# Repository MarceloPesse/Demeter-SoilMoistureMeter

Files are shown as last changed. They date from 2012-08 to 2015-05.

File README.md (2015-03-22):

Ah, the good old times.

This here is the final project for my Bachelor's degree in electrical engineering.
The group was composed of:
  - Marcelo Pesse a.k.a. Me
  - Ricardo Bonfá Alberico 
  - Jhonston Dalcin

This project is basically an Arduino Leonardo with a 4-chanel 18-bit resolution ADC and an Xbee module.
For the sensor we used an EC-5 soil moisture sensor from Decagon.
(http://www.decagon.com/products/soils/volumetric-water-content-sensors/ec-5-soil-moisture-small-area-of-influence/)

The hardware sends all the info via an XBee module to a PC running a Daemon.
The Daemon then sends the data to a server and everybody is happy.

This project was made 3 years ago, so it’s probably not my best work.

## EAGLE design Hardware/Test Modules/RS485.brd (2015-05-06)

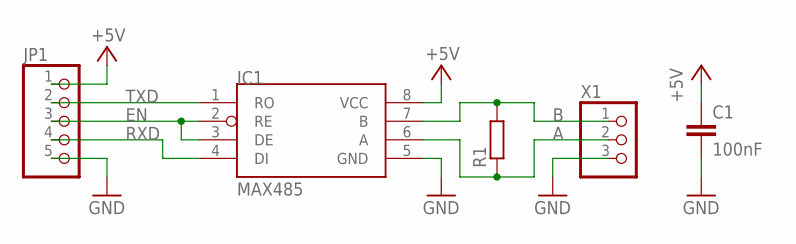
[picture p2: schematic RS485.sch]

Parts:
C1: 100nF; C0805K
IC1: MAX485; SO08
JP1: PINHD-1X5; 1X05
R1: R-EU_R0805; R0805
X1: W237-103

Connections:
+5V: C1.1, IC1.8 (VCC), JP1.1
A: IC1.6 (A), R1.1, X1.2
B: IC1.7 (B), R1.2, X1.1
EN: IC1.2 (RE), IC1.3 (DE), JP1.3
GND: C1.2, IC1.5 (GND), JP1.5, X1.3
RXD: IC1.4 (DI), JP1.4
TXD: IC1.1 (RO), JP1.2

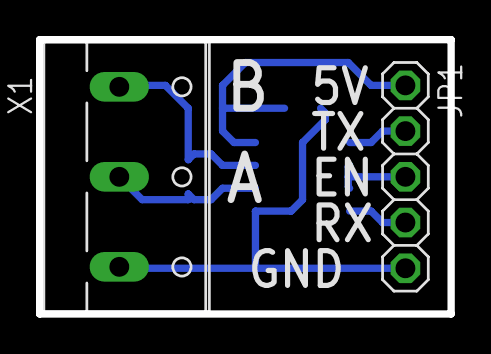
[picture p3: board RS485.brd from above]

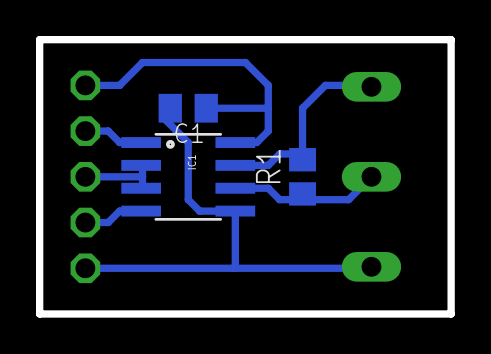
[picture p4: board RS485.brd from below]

Board: 2 copper layers, 22.9 x 15.2 mm, 5 parts (3 on the bottom side), 7 nets.

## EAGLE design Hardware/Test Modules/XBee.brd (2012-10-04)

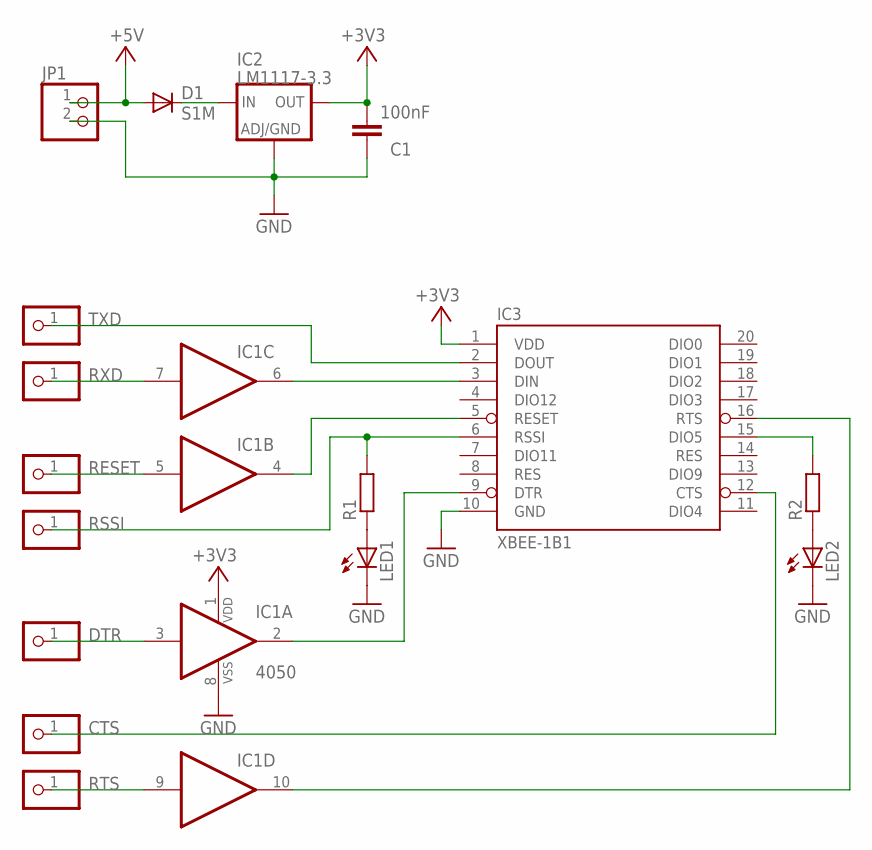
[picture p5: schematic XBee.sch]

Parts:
C1: 100nF; C0805K
D1: S1M; DO-214AC
IC1: 4050; SO16
IC2: LM1117-3.3; SOT223
IC3: XBEE-1B1; XBEE-1
JP1: PINHD-1X2; 1X02
JP2: TXD; 1X01
JP3: RXD; 1X01
JP4: RST; 1X01
JP5: RSSI; 1X01
JP6: DTR; 1X01
JP7: CTS; 1X01
JP8: RTS; 1X01
LED1, LED2: LED3MM
R1, R2: R-EU_R0805; R0805

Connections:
+3V3: C1.2, IC1.1 (VDD), IC2.2 (OUT), IC2.4 (OUT), IC3.1 (VDD)
+5V: D1.A, JP1.1
CTS: IC3.12 (CTS), JP7.1
DTR: IC1.3 (I), JP6.1
GND: C1.1, IC1.8 (VSS), IC2.1 (ADJ), IC3.10 (GND), JP1.2, LED1.K (C), LED2.K (C)
unnamed: D1.C, IC2.3 (IN)
unnamed: IC1.6 (O), IC3.3 (DIN)
unnamed: IC1.4 (O), IC3.5 (RESET)
unnamed: LED1.A, R1.1
unnamed: IC1.2 (O), IC3.9 (DTR)
unnamed: IC1.10 (O), IC3.16 (RTS)
unnamed: LED2.A, R2.1
unnamed: IC3.15 (DIO5), R2.2
RESET: IC1.5 (I), JP4.1
RSSI: IC3.6 (RSSI), JP5.1, R1.2
RTS: IC1.9 (I), JP8.1
RXD: IC1.7 (I), JP3.1
TXD: IC3.2 (DOUT), JP2.1

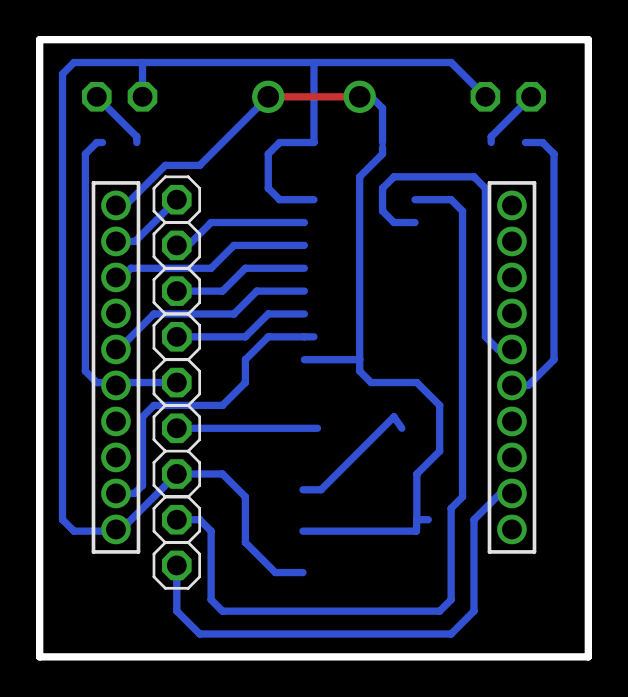
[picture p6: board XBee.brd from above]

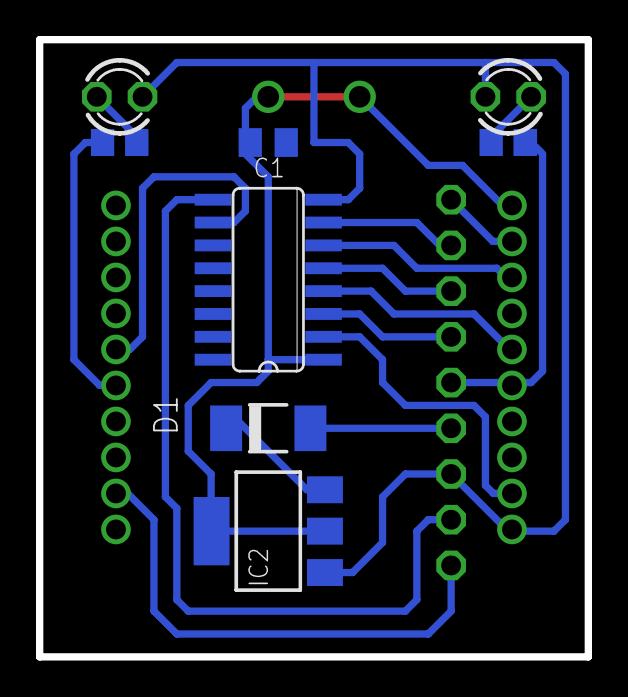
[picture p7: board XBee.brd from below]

Board: 2 copper layers, 30.5 x 34.3 mm, 17 parts (8 on the bottom side), 18 nets.

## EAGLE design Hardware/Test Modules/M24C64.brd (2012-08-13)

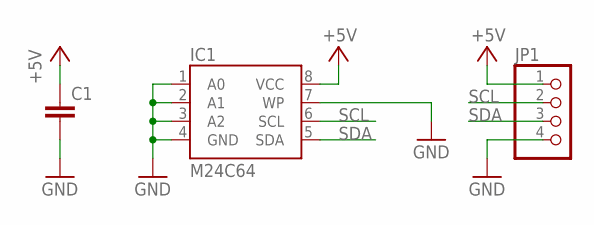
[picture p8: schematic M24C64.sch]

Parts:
C1: C-EUC0805K; C0805K
IC1: M24C64; SO08
JP1: PINHD-1X4; 1X04

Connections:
+5V: C1.1, IC1.8 (VCC), JP1.1
GND: C1.2, IC1.1 (A0), IC1.2 (A1), IC1.3 (A2), IC1.4 (GND), IC1.7 (WP), JP1.4
SCL: IC1.6 (SCL), JP1.2
SDA: IC1.5 (SDA), JP1.3

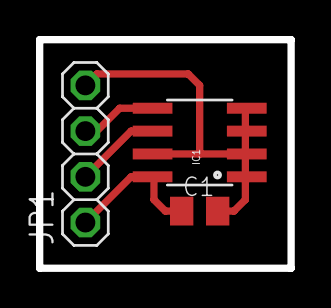
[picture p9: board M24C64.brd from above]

Board: 2 copper layers, 14.0 x 12.7 mm, 3 parts (0 on the bottom side), 4 nets.

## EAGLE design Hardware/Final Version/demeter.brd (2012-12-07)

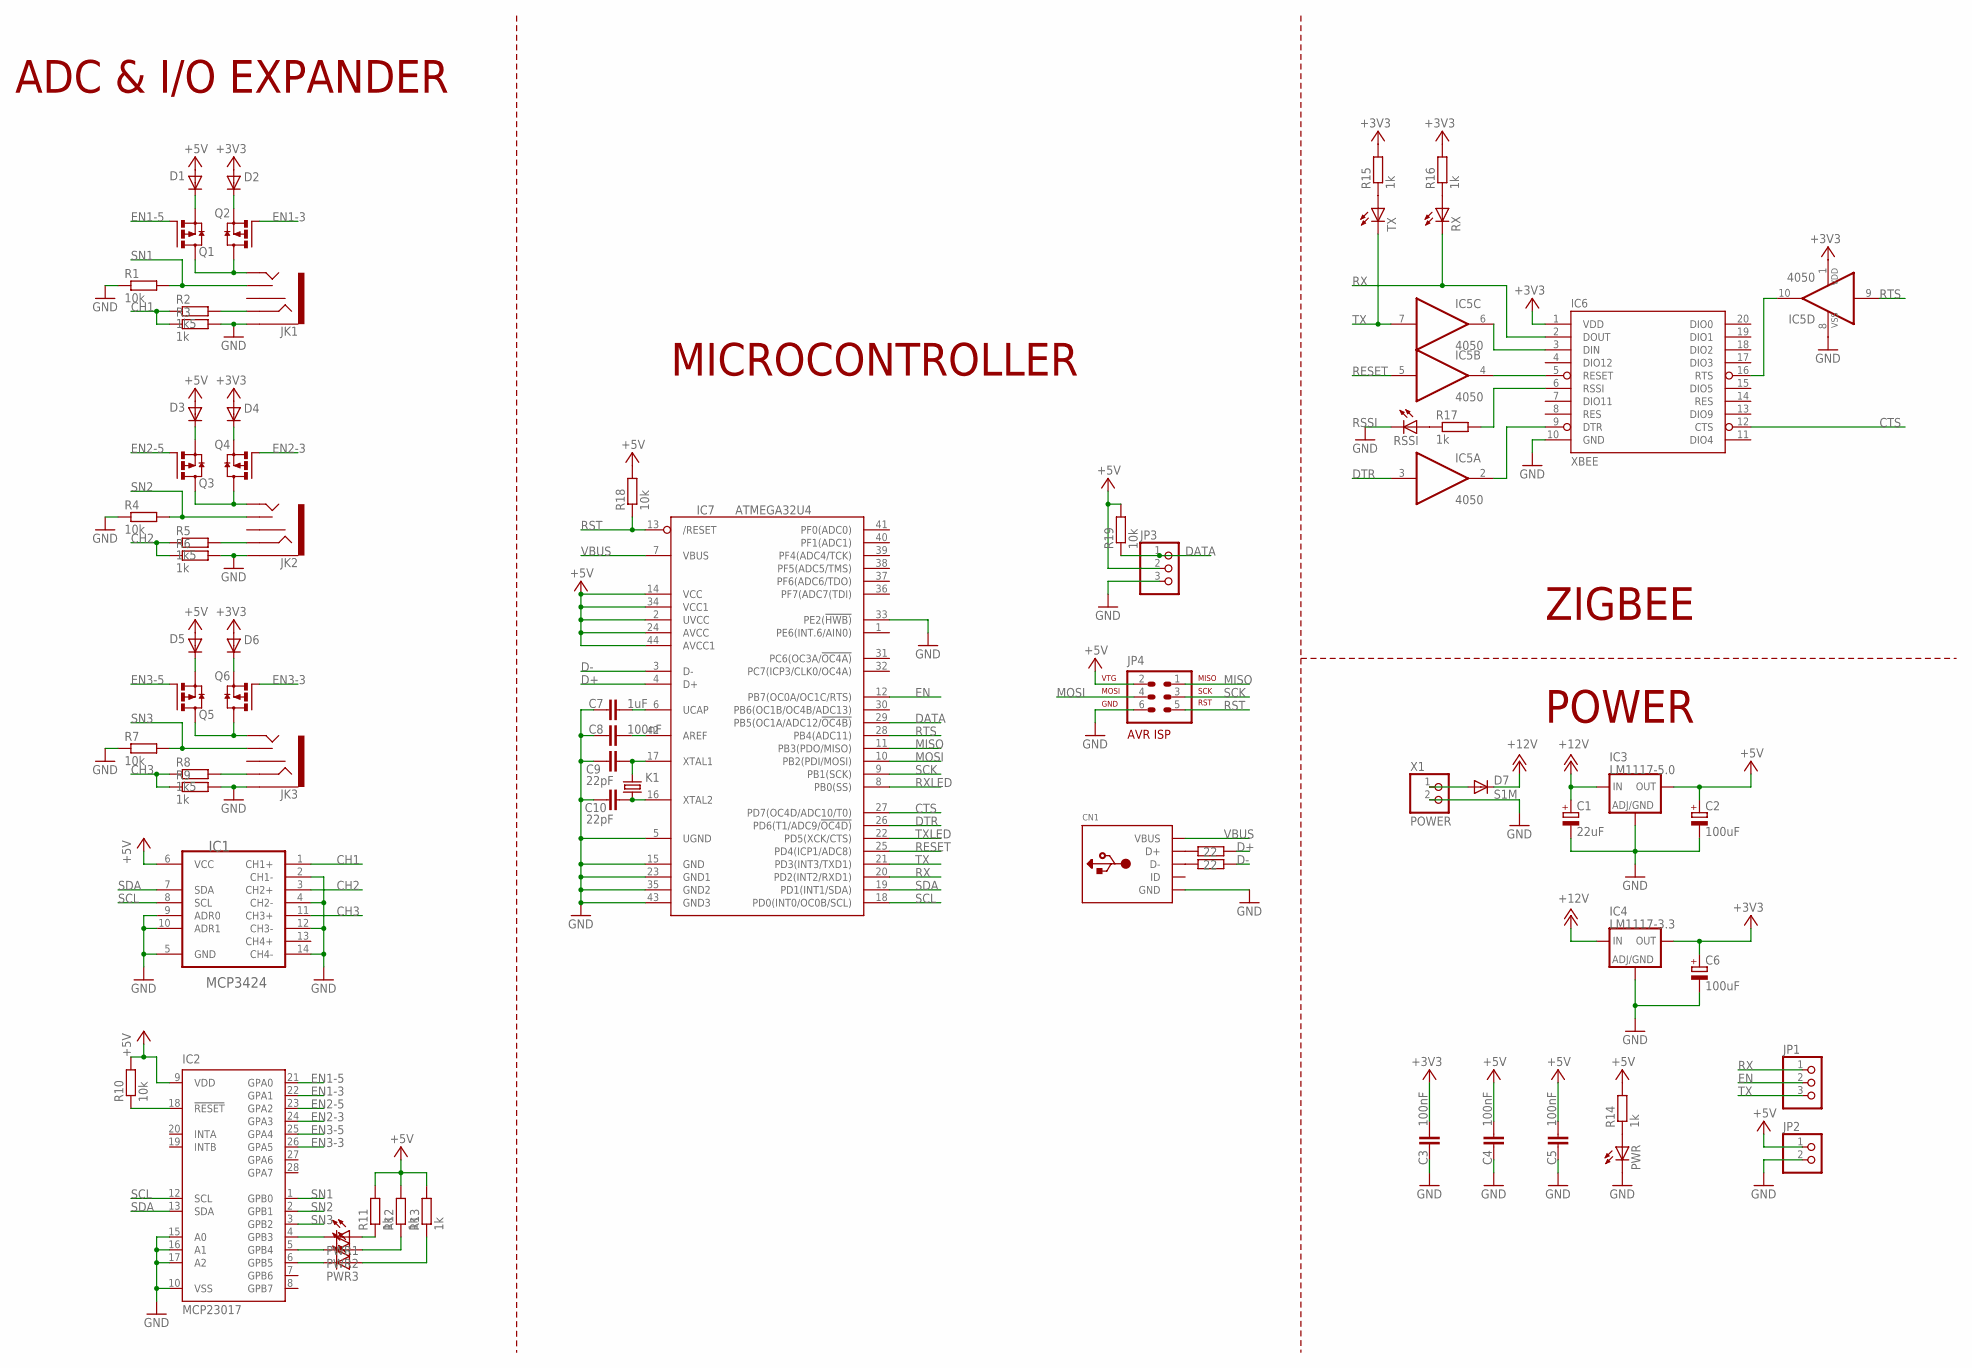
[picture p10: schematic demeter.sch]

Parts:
C1: 22uF; PANASONIC_D
C2, C6: 100uF; PANASONIC_D
C3, C4, C5, C8: 100nF; C0805K
C7: 1uF; C0805K
C9, C10: 22pF; C0805K
CN1: USBMINIB; USB-MINIB
D1, D2, D3, D4, D5, D6: MBR0520; SOD123
D7: S1M; DO-214AC
IC1: MCP3424; TSSOP14
IC2: MCP23017; SO28W
IC3: LM1117-5.0; DPACK
IC4: LM1117-3.3; DPACK
IC5: 4050; SO16
IC6: XBEE; XBEE-1
IC7: ATMEGA32U4; TQFP44
JK1, JK2, JK3: AUDIO-JACK2PTH; AUDIO-JACK
JP1, JP3: PINHD-1X3180; 1X03
JP2: PINHD-1X2; 1X02
JP4: AVR-ISP; AVR-ISP-6
K1: CRYSTALHC49UP; HC49UP
PWR, PWR1, PWR2, PWR3: LED0805; CHIP-LED0805
Q1, Q2, Q3, Q4, Q5, Q6: IRLML6402; SOT23
R1, R4, R7, R10, R18, R19: 10k; R0805
R2, R5, R8: 1k5; R0805
R3, R6, R9, R11, R12, R13, R14, R15, R16, R17: 1k; R0805
R20, R21: 22; R0805
RSSI: LED0805; CHIP-LED0805
RX: LED0805; CHIP-LED0805
TX: LED0805; CHIP-LED0805
X1: POWER; W237-102

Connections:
+3V3: C3.1, C6.+, D2.A, D4.A, D6.A, IC4.4 (OUT), IC5.1 (VDD), IC6.1 (VDD), R15.2, R16.2
+5V: C2.+, C4.1, C5.1, D1.A, D3.A, D5.A, IC1.6 (VCC), IC2.9 (VDD), IC3.4 (OUT), IC7.2 (UVCC), IC7.14 (VCC), IC7.24 (AVCC), IC7.34 (VCC1), IC7.44 (AVCC1), JP2.1, JP3.2, JP4.2 (VTG), R10.2, R11.2, R12.2, R13.2, R14.2, R18.2, R19.2
+12V: C1.+, D7.C, IC3.3 (IN), IC4.3 (IN)
CH1: IC1.1 (CH1+), R2.1, R3.1
CH2: IC1.3 (CH2+), R5.1, R6.1
CH3: IC1.11 (CH3+), R8.1, R9.1
CTS: IC6.12 (CTS), IC7.27 (PD7(OC4D/ADC10/T0))
D+: IC7.4 (D+), R20.1
D-: IC7.3 (D-), R21.1
DATA: IC7.29 (PB5(OC1A/ADC12/!OC4B)), JP3.1, R19.1
DTR: IC5.3 (I), IC7.26 (PD6(T1/ADC9/!OC4D))
EN: IC7.12 (PB7(OC0A/OC1C/RTS)), JP1.2
EN1-3: IC2.22 (GPA1), Q2.1 (G)
EN1-5: IC2.21 (GPA0), Q1.1 (G)
EN2-3: IC2.24 (GPA3), Q4.1 (G)
EN2-5: IC2.23 (GPA2), Q3.1 (G)
EN3-3: IC2.26 (GPA5), Q6.1 (G)
EN3-5: IC2.25 (GPA4), Q5.1 (G)
GND: C1.-, C2.-, C3.2, C4.2, C5.2, C6.-, C7.2, C8.2, C9.2, C10.2, CN1.GND, CN1.GND1 (GND), CN1.GND2 (GND), CN1.GND3 (GND), CN1.GND4 (GND), IC1.2 (CH1-), IC1.4 (CH2-), IC1.5 (GND), IC1.9 (ADR0), IC1.10 (ADR1), IC1.12 (CH3-), IC1.14 (CH4-), IC2.10 (VSS), IC2.15 (A0), IC2.16 (A1), IC2.17 (A2), IC3.1 (ADJ), IC4.1 (ADJ), IC5.8 (VSS), IC6.10 (GND), IC7.5 (UGND), IC7.15 (GND), IC7.23 (GND1), IC7.33 (PE2(!HWB)), IC7.35 (GND2), IC7.43 (GND3), JK1.SLEEVE, JK2.SLEEVE, JK3.SLEEVE, JP2.2, JP3.3, JP4.6 (GND), PWR.C, R1.1, R3.2, R4.1, R6.2, R7.1, R9.2, RSSI.C, X1.2
MISO: IC7.11 (PB3(PDO/MISO)), JP4.1 (MISO)
MOSI: IC7.10 (PB2(PDI/MOSI)), JP4.4 (MOSI)
unnamed: D7.A, X1.1
unnamed: PWR.A, R14.1
unnamed: IC5.6 (O), IC6.3 (DIN)
unnamed: IC5.4 (O), IC6.5 (RESET)
unnamed: PWR3.A, R13.1
unnamed: R17.1, RSSI.A
unnamed: IC5.2 (O), IC6.9 (DTR)
unnamed: IC5.10 (O), IC6.16 (RTS)
unnamed: IC2.6 (GPB5), PWR3.C
unnamed: IC2.4 (GPB3), PWR1.C
unnamed: IC2.18 (!RESET), R10.1
unnamed: JK1.TIP, Q1.3 (D), Q2.3 (D)
unnamed: D1.C, Q1.2 (S)
unnamed: D2.C, Q2.2 (S)
unnamed: JK2.TIP, Q3.3 (D), Q4.3 (D)
unnamed: D3.C, Q3.2 (S)
unnamed: D4.C, Q4.2 (S)
unnamed: JK3.TIP, Q5.3 (D), Q6.3 (D)
unnamed: D5.C, Q5.2 (S)
unnamed: D6.C, Q6.2 (S)
unnamed: PWR2.A, R12.1
unnamed: PWR1.A, R11.1
unnamed: C7.1, IC7.6 (UCAP)
unnamed: C8.1, IC7.42 (AREF)
unnamed: C9.1, IC7.17 (XTAL1), K1.2
unnamed: C10.1, IC7.16 (XTAL2), K1.1
unnamed: CN1.D+, R20.2
unnamed: CN1.D-, R21.2
unnamed: JK1.RING, R2.2
unnamed: JK2.RING, R5.2
unnamed: IC2.5 (GPB4), PWR2.C
unnamed: JK3.RING, R8.2
unnamed: R15.1, TX.A
unnamed: R16.1, RX.A
RESET: IC5.5 (I), IC7.25 (PD4(ICP1/ADC8))
RSSI: IC6.6 (RSSI), R17.2
RST: IC7.13 (/RESET), JP4.5 (RST), R18.1
RTS: IC5.9 (I), IC7.28 (PB4(ADC11))
RX: IC6.2 (DOUT), IC7.20 (PD2(INT2/RXD1)), JP1.1, RX.C
RXLED: IC7.8 (PB0(SS))
SCK: IC7.9 (PB1(SCK)), JP4.3 (SCK)
SCL: IC1.8 (SCL), IC2.12 (SCL), IC7.18 (PD0(INT0/OC0B/SCL))
SDA: IC1.7 (SDA), IC2.13 (SDA), IC7.19 (PD1(INT1/SDA))
SN1: IC2.1 (GPB0), JK1.TSH, R1.2
SN2: IC2.2 (GPB1), JK2.TSH, R4.2
SN3: IC2.3 (GPB2), JK3.TSH, R7.2
TX: IC5.7 (I), IC7.21 (PD3(INT3/TXD1)), JP1.3, TX.C
TXLED: IC7.22 (PD5(XCK/CTS))
VBUS: CN1.VBUS, IC7.7 (VBUS)

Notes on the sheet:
ADC & I/O EXPANDER
ZIGBEE
POWER
MICROCONTROLLER

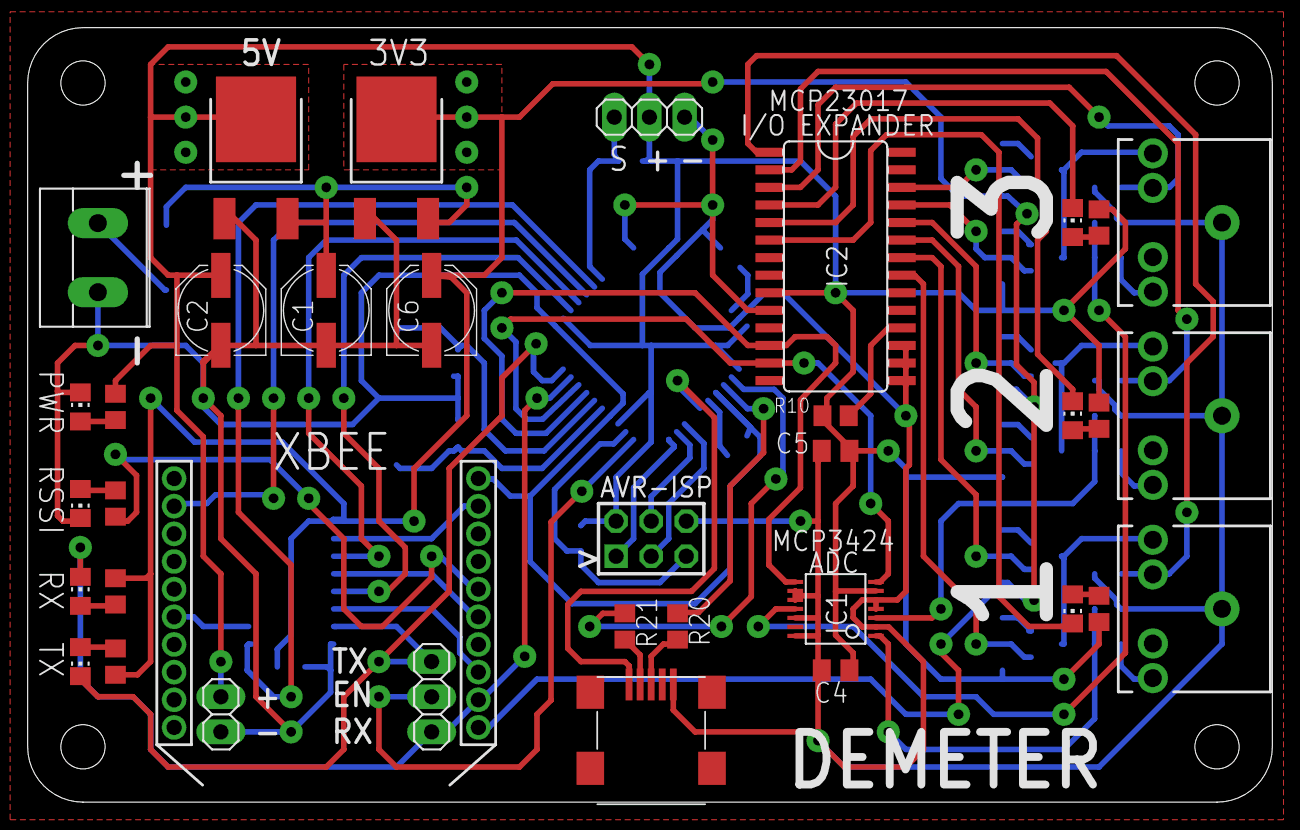
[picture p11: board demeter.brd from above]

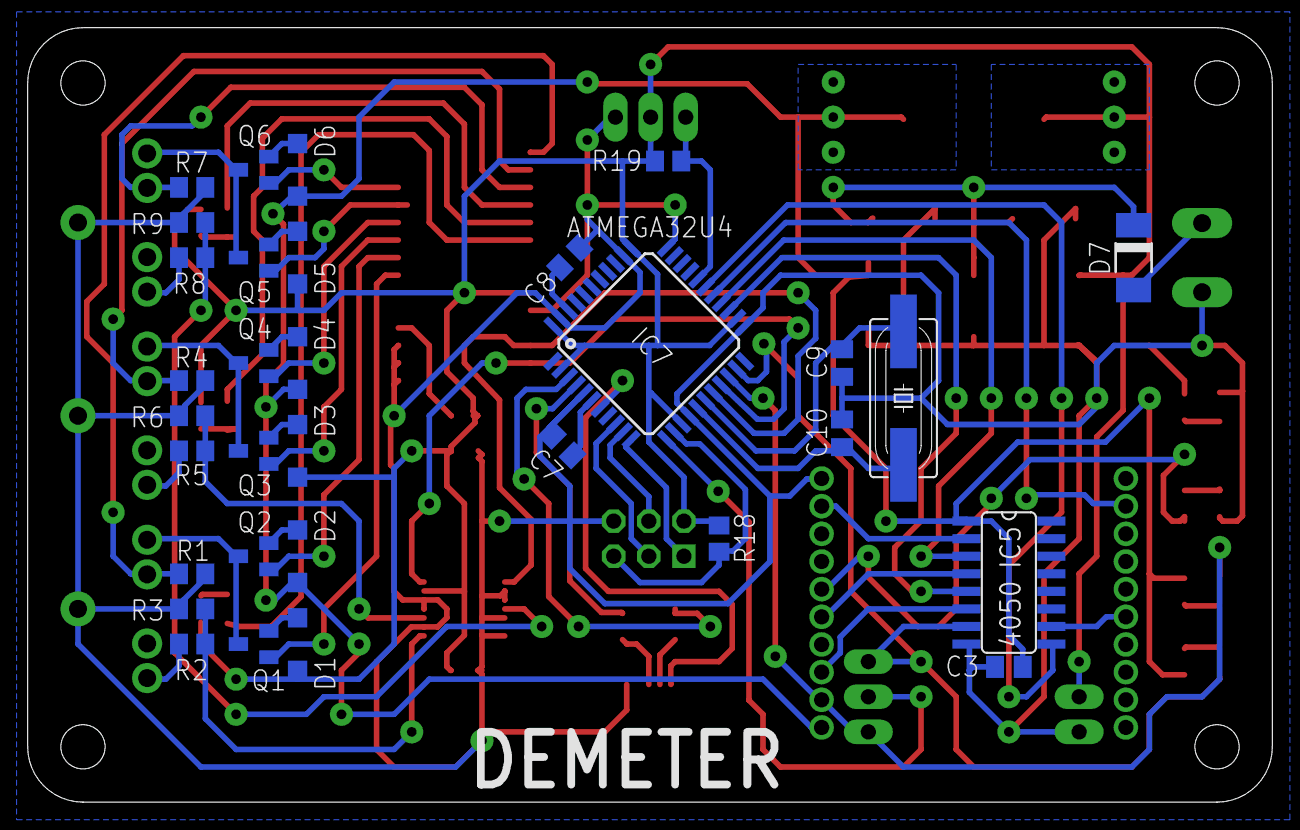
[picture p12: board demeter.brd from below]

Board: 2 copper layers, 90.0 x 56.0 mm, 69 parts (32 on the bottom side), 68 nets.

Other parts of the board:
U$6: DP9056_V1

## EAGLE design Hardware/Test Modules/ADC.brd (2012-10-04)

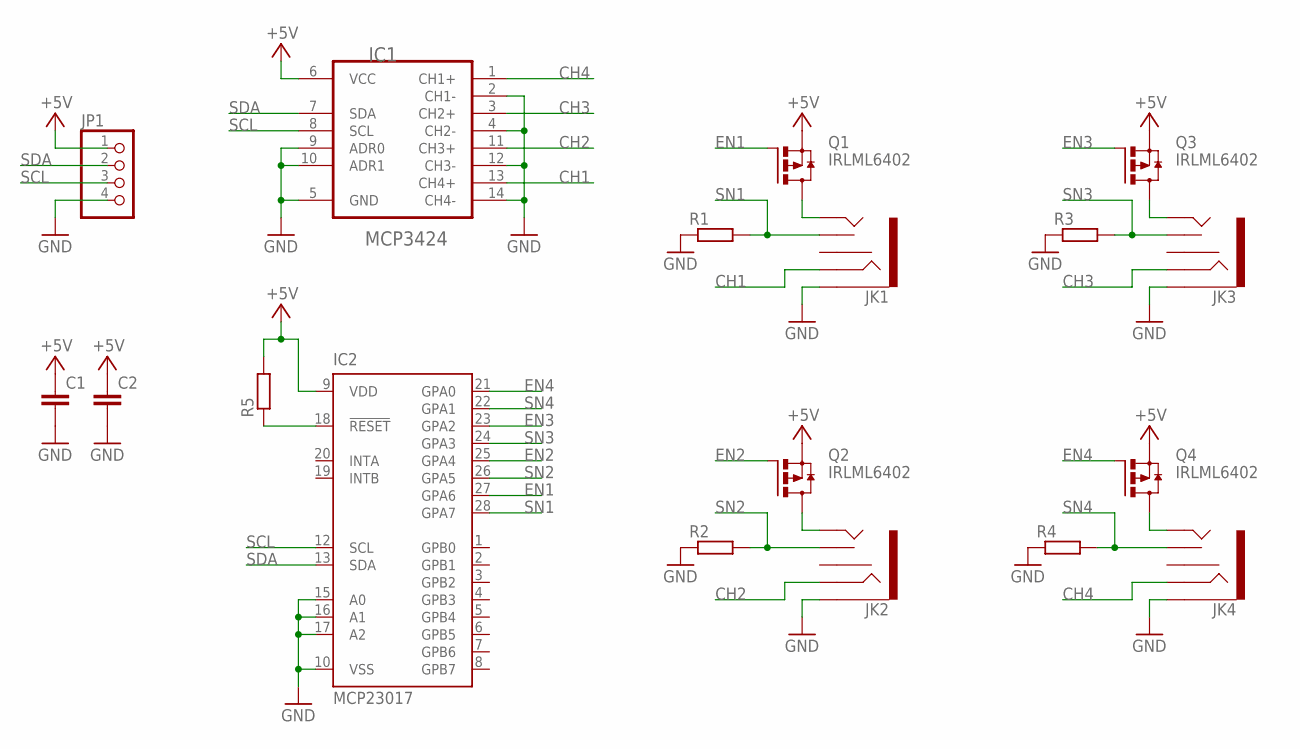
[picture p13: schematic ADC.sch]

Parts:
C1, C2: C-EUC0805K; C0805K
IC1: MCP3424; SO14
IC2: MCP23017; SO28W
JK1, JK2, JK3, JK4: AUDIO-JACK2PTH; AUDIO-JACK
JP1: PINHD-1X4; 1X04
Q1, Q2, Q3, Q4: IRLML6402; SOT23
R1, R2, R3, R4, R5: R-EU_R0805; R0805

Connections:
+5V: C1.1, C2.1, IC1.6 (VCC), IC2.9 (VDD), JP1.1, Q1.2 (S), Q2.2 (S), Q3.2 (S), Q4.2 (S), R5.2
CH1: IC1.13 (CH4+), JK1.RING
CH2: IC1.11 (CH3+), JK2.RING
CH3: IC1.3 (CH2+), JK3.RING
CH4: IC1.1 (CH1+), JK4.RING
EN1: IC2.27 (GPA6), Q1.1 (G)
EN2: IC2.25 (GPA4), Q2.1 (G)
EN3: IC2.23 (GPA2), Q3.1 (G)
EN4: IC2.21 (GPA0), Q4.1 (G)
GND: C1.2, C2.2, IC1.2 (CH1-), IC1.4 (CH2-), IC1.5 (GND), IC1.9 (ADR0), IC1.10 (ADR1), IC1.12 (CH3-), IC1.14 (CH4-), IC2.10 (VSS), IC2.15 (A0), IC2.16 (A1), IC2.17 (A2), JK1.SLEEVE, JK2.SLEEVE, JK3.SLEEVE, JK4.SLEEVE, JP1.4, R1.1, R2.1, R3.1, R4.1
unnamed: JK1.TIP, Q1.3 (D)
unnamed: IC2.18 (!RESET), R5.1
unnamed: JK2.TIP, Q2.3 (D)
unnamed: JK3.TIP, Q3.3 (D)
unnamed: JK4.TIP, Q4.3 (D)
SCL: IC1.8 (SCL), IC2.12 (SCL), JP1.3
SDA: IC1.7 (SDA), IC2.13 (SDA), JP1.2
SN1: IC2.28 (GPA7), JK1.TSH, R1.2
SN2: IC2.26 (GPA5), JK2.TSH, R2.2
SN3: IC2.24 (GPA3), JK3.TSH, R3.2
SN4: IC2.22 (GPA1), JK4.TSH, R4.2



Board: 2 copper layers, 54.6 x 50.8 mm, 18 parts (13 on the bottom side), 21 nets.

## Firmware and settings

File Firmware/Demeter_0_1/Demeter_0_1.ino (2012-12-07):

#include <Wire.h>
#include <EEPROM.h>

#include <DemeterMCP.h>
#include <DemeterADC.h>
#include <DemeterDHT.h>
#include <DemeterCOM.h>

#include "DemeterPIN.h"

demeterMCP mcp;
demeterADC adc;
demeterDHT dht;
demeterCOM com;

String id;

//Board{sen1,ten1,sen2,ten2,sen3,ten3}
Board board = { EEPROM.read(EE_SEN1), EEPROM.read(EE_TEN1),
                EEPROM.read(EE_SEN2), EEPROM.read(EE_TEN2),
                EEPROM.read(EE_SEN3), EEPROM.read(EE_TEN3) };

//Sensor{v5,v3,led,sen,adc}
Sensor sensor1 = {SEN_5V1, SEN_3V1, SEN_LED1, SEN_SN1, SEN_ADC1 };
Sensor sensor2 = {SEN_5V2, SEN_3V2, SEN_LED2, SEN_SN2, SEN_ADC2 };
Sensor sensor3 = {SEN_5V3, SEN_3V3, SEN_LED3, SEN_SN3, SEN_ADC3 };

#define b_max 4
char buff[b_max+1];

void setup() {
  com.begin(XBEE_RESET, RS485_EN);
  mcp.begin();
  dht.begin(SEN_DHT);
  
  sensorBegin(&sensor1);
  sensorBegin(&sensor2);
  sensorBegin(&sensor3);
  
  /*
  EEPROM.write(EE_BOARD, 1);
  EEPROM.write(EE_SEN1, 3);
  EEPROM.write(EE_TEN1, 3);
  EEPROM.write(EE_SEN2, 0);
  EEPROM.write(EE_TEN2, 3);
  EEPROM.write(EE_SEN3, 0);
  EEPROM.write(EE_TEN3, 3);
  */
  
  id = String(EEPROM.read(EE_BOARD), HEX);
  if(EEPROM.read(EE_BOARD) < 16){
    id.concat(id[0]);
    id.setCharAt(0, '0');
  }
  id.toUpperCase();
}

void loop() {
  while (Serial1.available() > 0){
    for(int i = 0; i < b_max; i++){
      buff[i] = buff[i+1];
    }
    buff[b_max] = Serial1.read();
    if(buff[0] == '#' & buff[1] == id[0] & buff[2] == id[1] & buff[3] == ':'){
      if(buff[4] == '1') com.sensor(EEPROM.read(EE_BOARD), 1, board.sen1, sensorRead(&sensor1, board.ten1)/2 );
      if(buff[4] == '2') com.sensor(EEPROM.read(EE_BOARD), 2, board.sen2, sensorRead(&sensor2, board.ten2)/2 );
      if(buff[4] == '3') com.sensor(EEPROM.read(EE_BOARD), 3, board.sen3, sensorRead(&sensor3, board.ten3)/2 );
      if(buff[4] == '4') com.sensor(EEPROM.read(EE_BOARD), 4, 1, dht.temperature() );
      if(buff[4] == '5') com.sensor(EEPROM.read(EE_BOARD), 5, 2, dht.humidity() );
    }
  }
}

void sensorBegin (Sensor* sensor){
  mcp.pinMode(sensor->v5, OUTPUT);
  mcp.pinMode(sensor->v3, OUTPUT);
  mcp.pinMode(sensor->led, OUTPUT);
  mcp.pinMode(sensor->sen, INPUT);

  mcp.digitalWrite(sensor->v5, HIGH);
  mcp.digitalWrite(sensor->v3, HIGH);
  mcp.digitalWrite(sensor->led, HIGH);
}

int32_t sensorRead (Sensor* sensor, byte tensao){
  mcp.digitalWrite(sensor->led, LOW);
  
  if (tensao == 5) mcp.digitalWrite(sensor->v5, LOW);
  else mcp.digitalWrite(sensor->v3, LOW);
  
  delay(10);
  
  int32_t data;
  adc.config(sensor->adc);
  if (!adc.read(data)) Serial.print("Error");
  
  mcp.digitalWrite(sensor->v5, HIGH);
  mcp.digitalWrite(sensor->v3, HIGH);
  
  mcp.digitalWrite(sensor->led, HIGH);
  
  return data;
}

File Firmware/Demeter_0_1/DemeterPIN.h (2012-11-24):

#define XBEE_RESET 4
#define XBEE_DTR 12
#define XBEE_CTS 6
#define XBEE_RTS 8

#define SEN_DHT 9

#define RS485_EN 11

#define SEN_LED1 13
#define SEN_LED2 12
#define SEN_LED3 11
#define SEN_SN1 8
#define SEN_SN2 9
#define SEN_SN3 10

#define SEN_5V1 0
#define SEN_3V1 1
#define SEN_5V2 2
#define SEN_3V2 3
#define SEN_5V3 4
#define SEN_3V3 5

#define SEN_ADC1 1
#define SEN_ADC2 2
#define SEN_ADC3 3

#define EE_BOARD 0
#define EE_SEN1 1
#define EE_TEN1 2
#define EE_SEN2 3
#define EE_TEN2 4
#define EE_SEN3 5
#define EE_TEN3 6

struct Sensor{
  uint8_t v5;
  uint8_t v3;
  uint8_t led;
  uint8_t sen;
  uint8_t adc;
};

struct Board{
  uint8_t sen1;
  uint8_t ten1;
  uint8_t sen2;
  uint8_t ten2;
  uint8_t sen3;
  uint8_t ten3;
};

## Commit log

2012-11-19 Inclusão da última versão do SI (integrada com parte gráfica, faltando principalmente correção do jquery do setor e o sistema de mapas da fazenda, além de funcionalidades "opcionais" como previsão do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
2012-11-24 deletando tudo do SI pois não conseguia dar commit, proximo tera tudo de novo
2012-11-24 coltando SI para dar certo commit. nessa versão tem o gráfico puxando dados direto do banco, problema com jquery resolvido
2012-11-29 models modificado para atender as novas mudancas de integracao com C#
2012-12-05 pagina da fazenda busca por todos os setores e mostra no mapa suas posicoes e cores baseadas na comparacao com umidade de refencia
2012-12-06 alteracao de posicao do setor clicando no mapa funfando!!
2012-12-07 commit com tudo funcionando lindamente, pronto para apresentar! =D
2015-03-22 - Cosmetic overall of the files names and system
    [ADC.brd, ADC.sch, Farnell - Prototipo 1.xlsx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]
2015-05-06 - Some minor changes on the Silk-Screen of the RS485 module
    [RS485.brd, RS485.sch]
